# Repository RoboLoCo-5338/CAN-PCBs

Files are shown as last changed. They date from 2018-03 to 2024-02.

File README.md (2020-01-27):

# Quick Overview
The goal of this project was to create a Printed Circuit Board (PCB) for our Controller Area Network (CAN) Bus using a star topology for our robot.
You can learn more CAN and various topologies [here](http://www.mindsensors.com/content/86-can-and-its-topology).
Each v7 and v8 board was designed to accommodate up to **10** CAN devices, i.e., 8 Victor SPXs or Talon SRXs along with a Power Distribution Panel and RoboRIO.
The v9 board allows for up to **24** connections per board including a "ground" connection for each. 

Easy expansion is possible by linking multiple boards to each other directly to increase the total number of connections, i.e., 2 boards allows for 18 total connections.
When combined with code that is fault-tolerant, it can be possible to recover from the loss or disconnection of a device on the bus, which would be catastrophic on a daisy-chained network.

This project contains two folders, one for the PCB that our team currently uses on our competition robot, as well as one for the PCB that we plan to handout at the Chesapeake District Championships.

We have used these boards since the 2017/2018 season and are satisfied with their excellent performance and ease of wiring.

# RoboLoCo
* [RoboLoCo's Website](https://www.roboloco.org)
* [CAN PCB Website](https://www.roboloco.org/canpcb)

# PCB Specifics
The PCB uses screw terminals to connect devices to the bus.
They, such as the ones we use from [Amazon](https://www.amazon.com/gp/product/B00EZ3QPCU/), are standard Wago 237-132 screw terminals.
We have found it ideal when the CAN wires are placed in ferrules, such as the ones we use from [Automation Direct](https://www.automationdirect.com/adc/Shopping/Catalog/Wiring_Solutions/BM_Group_-_Wire_End_Connectors/Insulated_Ferrules/DIN_Color_Single_Wire/BM-00601), but that is not required.
The terminating 120Ω resistors are optional in almost every use case and are for extra future functionality to not require the use of two devices with built in termination.
However, should a 120Ω resistors be added, its corresponding optional male headers **must** be added to enable or disable the resistors.

# Holder and Mounting Info
The PCBs' holders were also designed to fit on standard 1" pegboard via zip ties or bolts.
The holes on each holder was designed to accommodate heat-set inserts, such as the ones we use from [McMaster-Carr](https://www.mcmaster.com/#93365a132/=1b46wa6), to provide threaded holes.
The board then uses at up to 6 0.1875" #6-32 bolts depending on the PCB, such as the ones we use from [McMaster-Carr](https://www.mcmaster.com/#91864a085/), to be anchored down.
Particularly, the spacing around the center holes allows for the use of thumb screws, such as the ones we use from [Amazon](https://www.amazon.com/Anodized-Aluminum-Computer-Thumbscrews-Thread/dp/B00BGZ1OFI/), to allow for easier insertion and removal before final mounting.

# Files
For each board, the files provided include the Eagle BRD, SCH, and EPF files, as well as STL files for the 3D printed holder.
The files are compatible with [Eagle](https://www.autodesk.com/products/eagle/free-download) 8.0 and up.
The DRU file used by our PCB fab, [Silver Circuits](http://www.custompcb.com), is also provided. However, the Eagles files can be used to manufacture the board with the PCB fab of your choice
For each board, there are also images of the board layout and schematic in Eagle, a render of the holder, and images of the actual PCB in the 3D-printed holder.

# Versions

## Star Board v7 (aka Competition PCB)
This is a current production board that is tested and in use on RoboLoCo's 2019 robot. 

## Star Board v8
This is incomplete and under active development. 

## Star Board Wide v9
### Overview
This is a current production board that is tested and in use on RoboLoCo's 2020 robot. 

### "Ground" Connection
For FRC the "ground" on the board should be used with the sheild on sheilded twisted pair cable. RoboLoCo is leaving it to float. 
It's possible to attach to either the neg power or chassis. However both options carry slight risks during inspection. If attached to the 
chassis any instance of the shield touching **any** electrical connections even slightly will cause the chassis to be electrically connected 
to the electrical system. A related issue happens if using the chassis for the sheild. 

# Final Notes
If you have any questions, feel reach out and contact us at contact@roboloco.org.
Please share with us your experiences if you use them and any feedback you have!

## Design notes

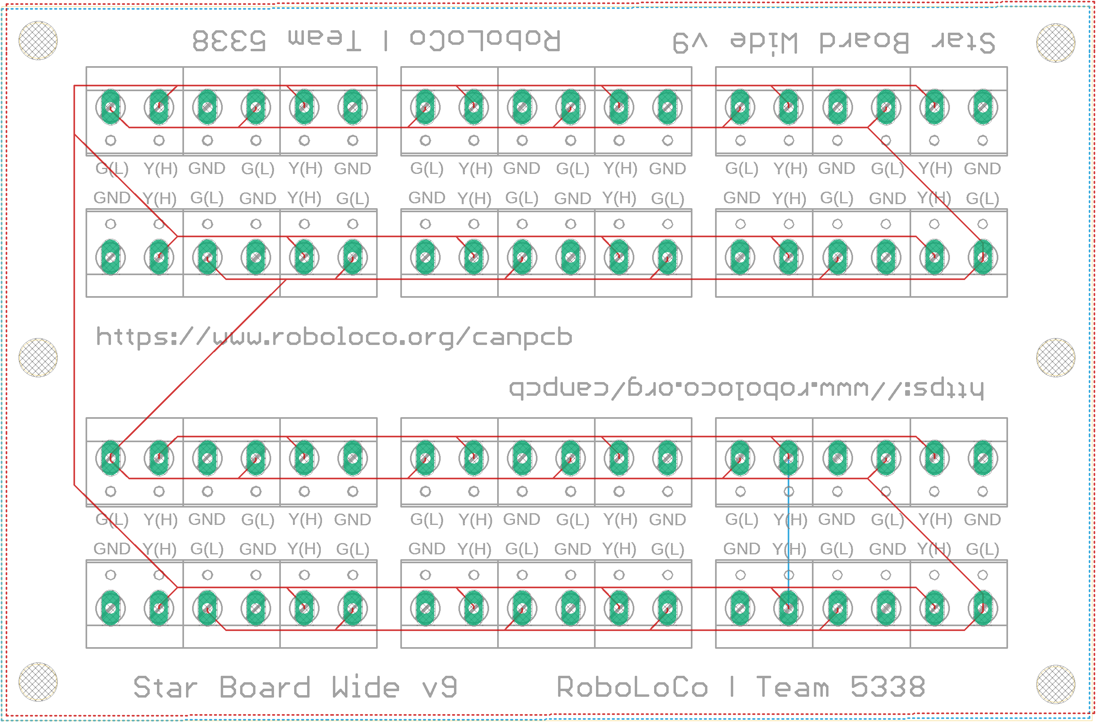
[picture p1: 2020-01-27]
Star Board Wide v9/Images/board.png

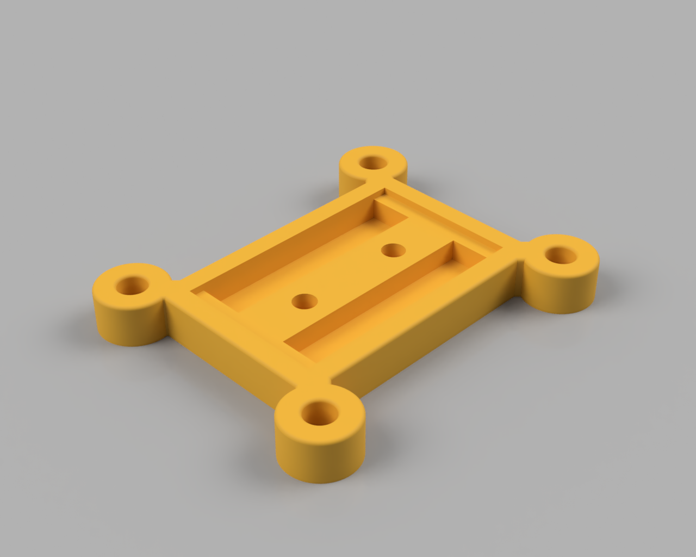
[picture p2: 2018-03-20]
District Champs PCB - Depricated/Holder/Holder.PNG

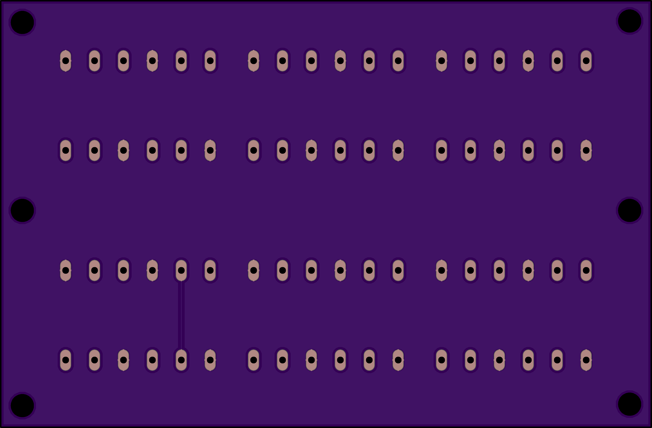
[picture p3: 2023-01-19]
Star Board Wide v9/PCB/FAB_Files/bottom.png

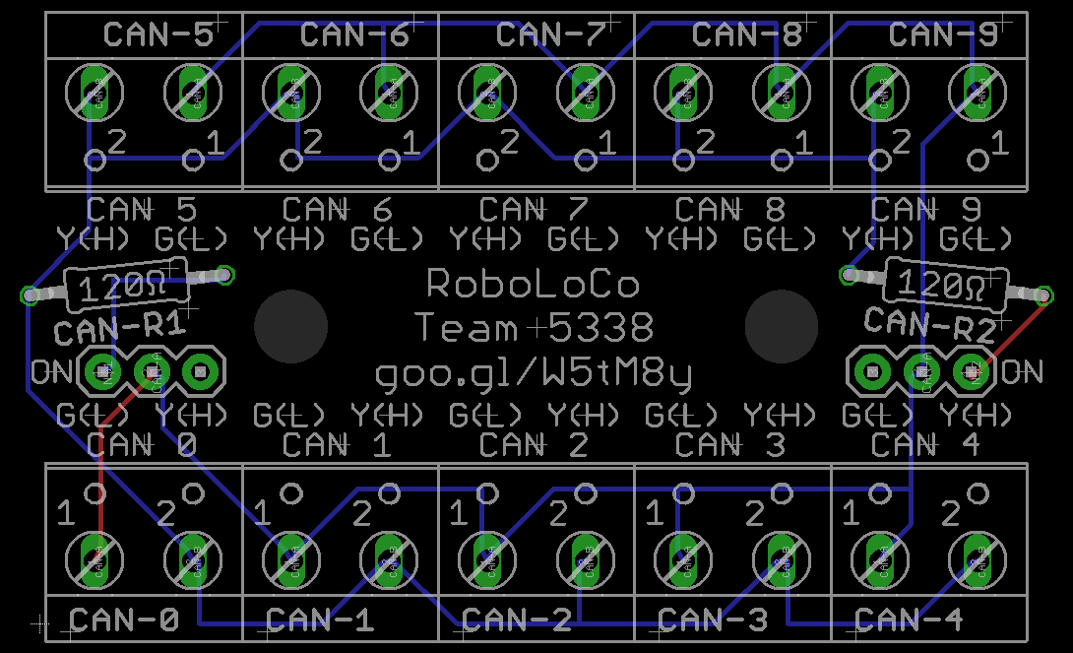
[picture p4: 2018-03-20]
District Champs PCB - Depricated/PCB/PCB.png

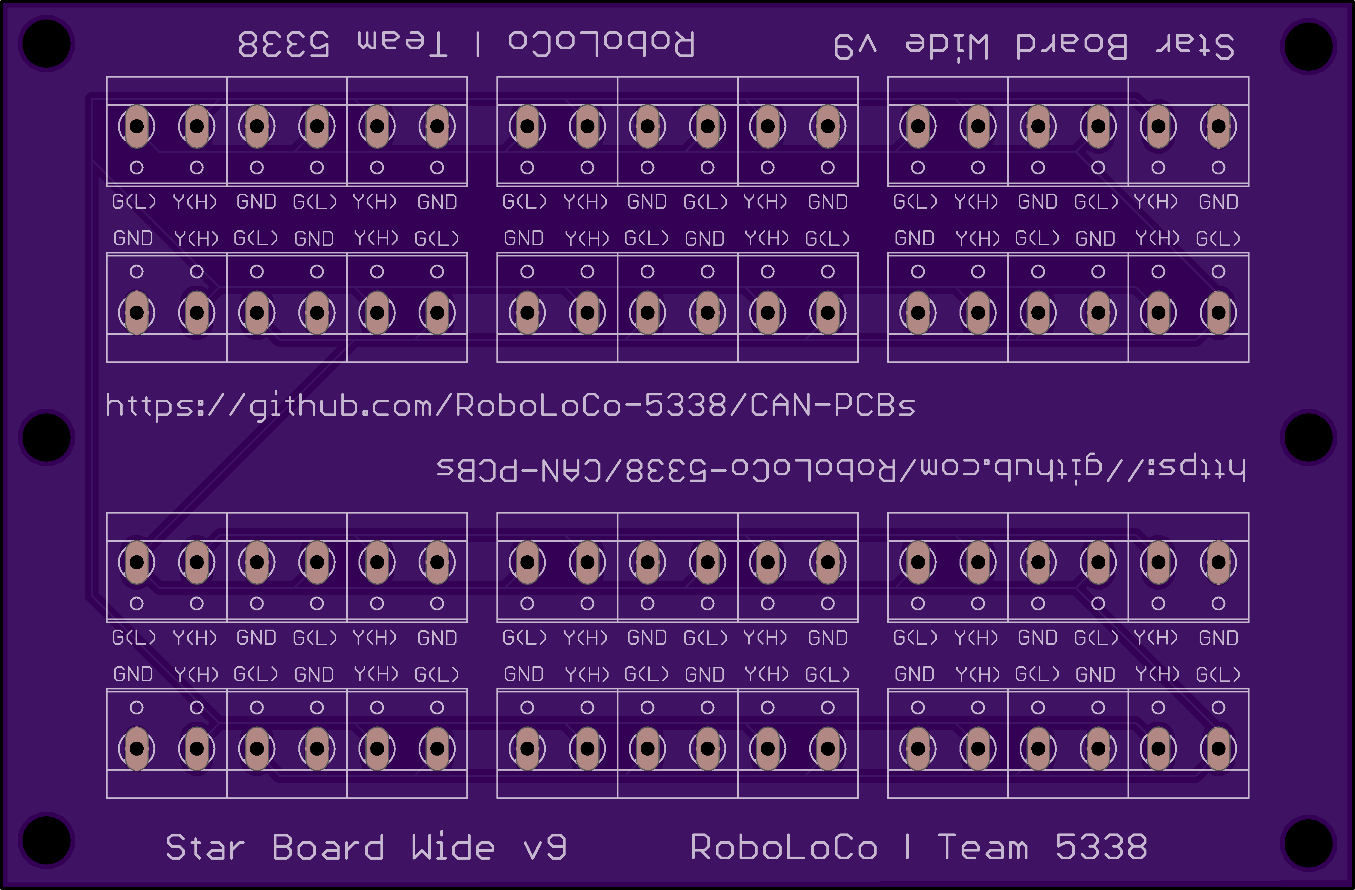
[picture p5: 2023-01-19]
Star Board Wide v9/PCB/FAB_Files/top.png

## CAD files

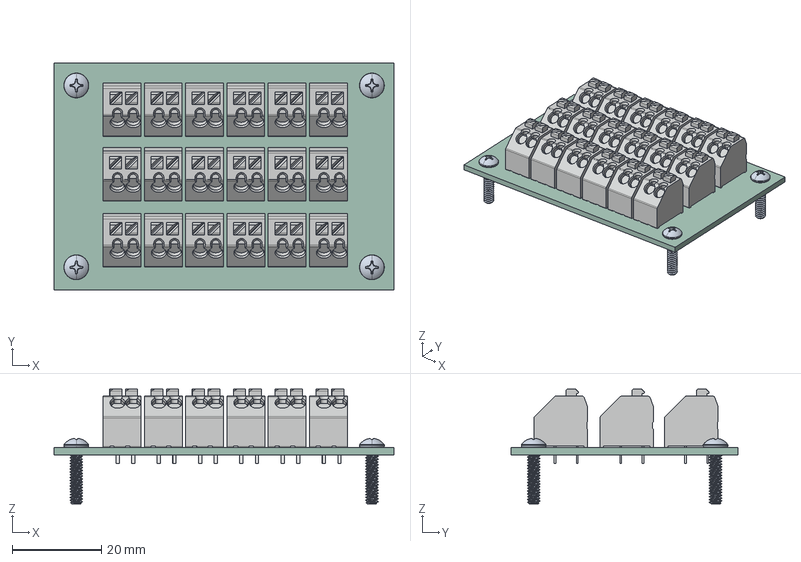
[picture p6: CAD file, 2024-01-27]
Star Board v10/Model/CAN_board.step
76.2 x 50.8 x 25.8 mm
91772A110_Passivated 18-8 Stainless Steel Pan Head Phillips Screw x 4
_autosave-CAN_board PCB

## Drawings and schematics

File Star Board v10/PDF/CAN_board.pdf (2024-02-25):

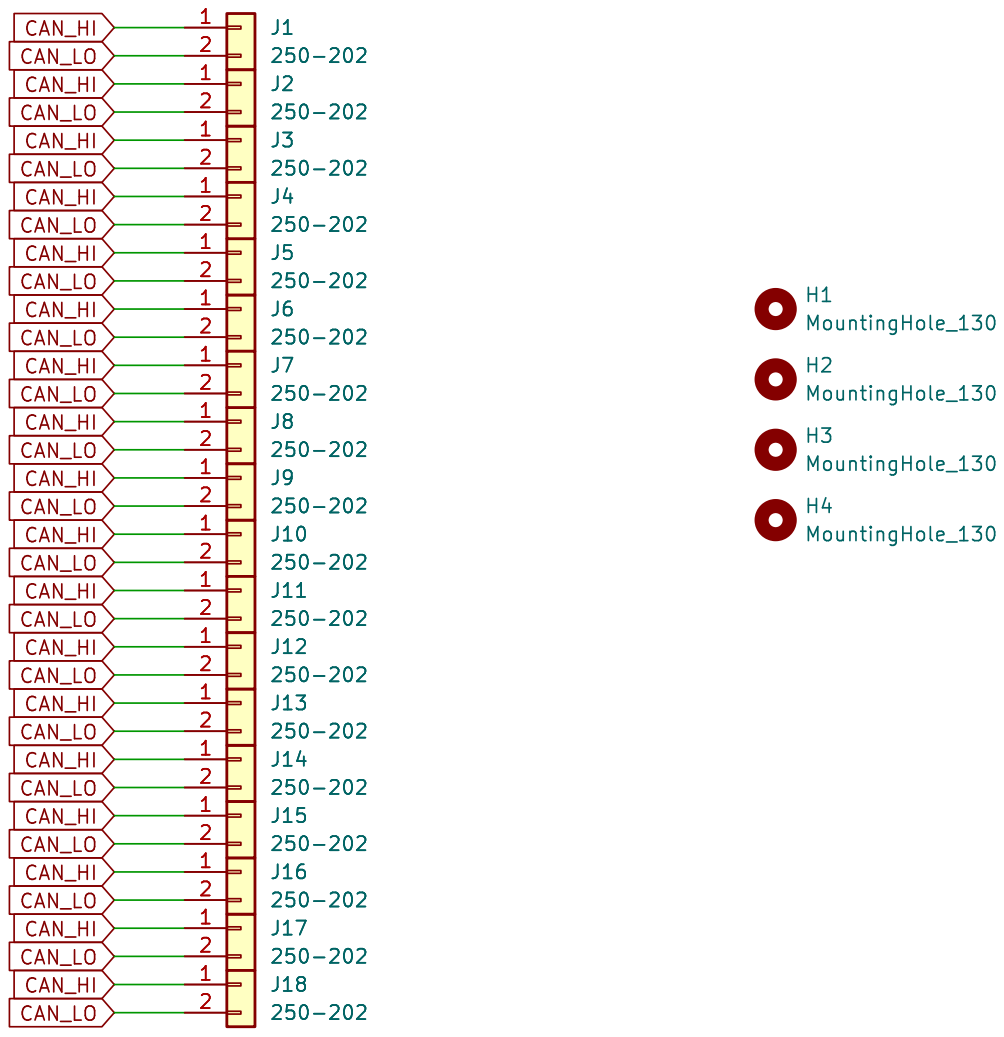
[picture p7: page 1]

Id: 1/1 Title: File: CAN_board.kicad_sch Sheet: / 12

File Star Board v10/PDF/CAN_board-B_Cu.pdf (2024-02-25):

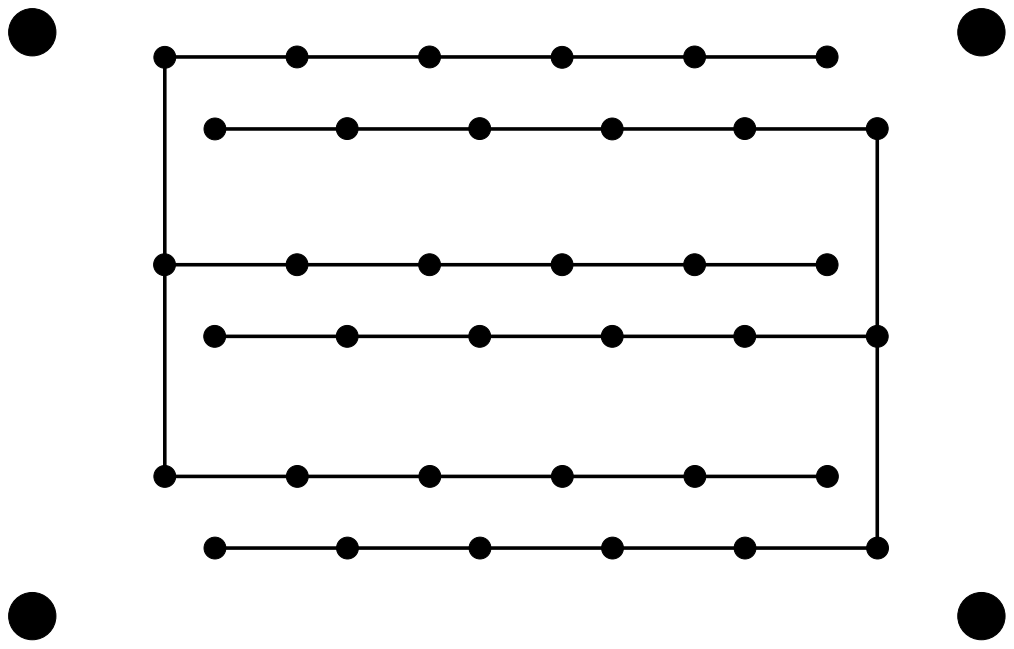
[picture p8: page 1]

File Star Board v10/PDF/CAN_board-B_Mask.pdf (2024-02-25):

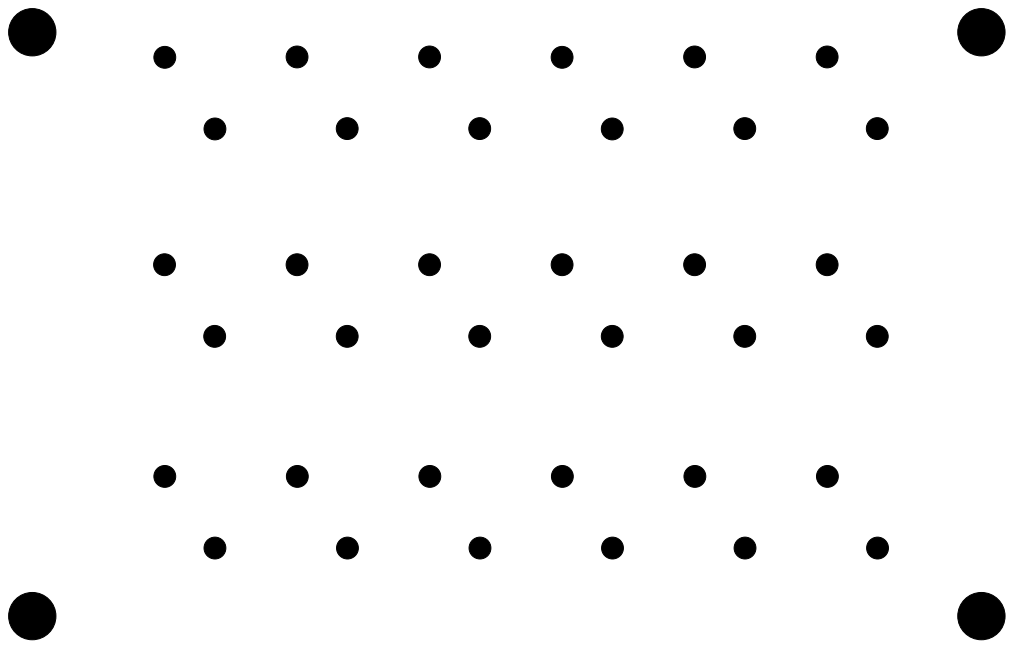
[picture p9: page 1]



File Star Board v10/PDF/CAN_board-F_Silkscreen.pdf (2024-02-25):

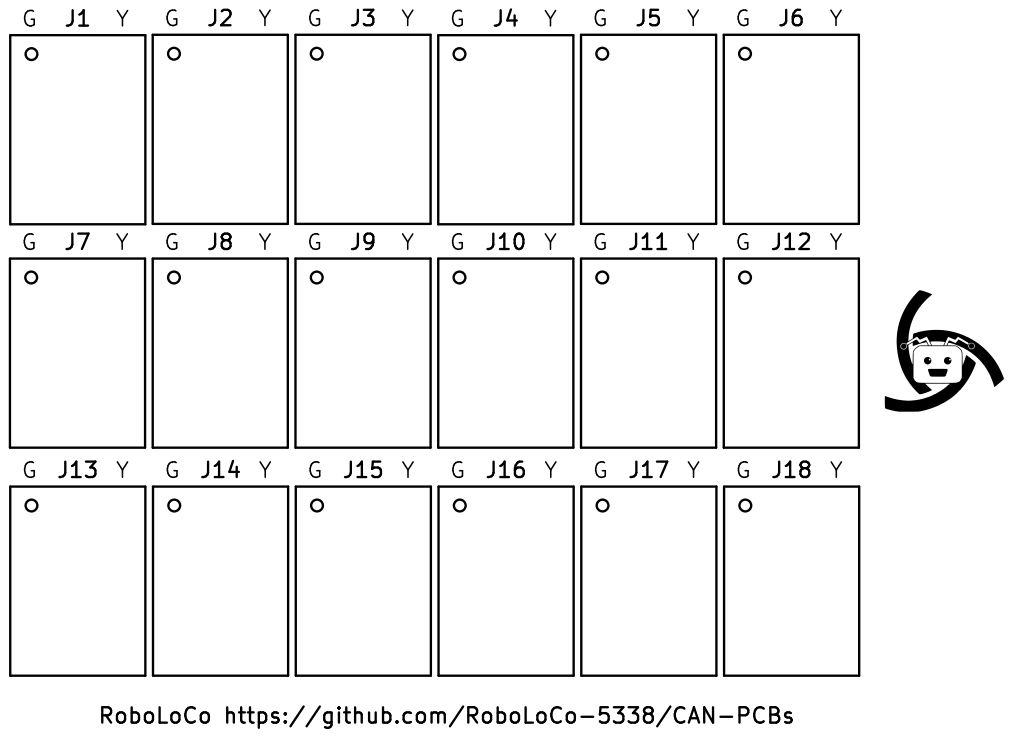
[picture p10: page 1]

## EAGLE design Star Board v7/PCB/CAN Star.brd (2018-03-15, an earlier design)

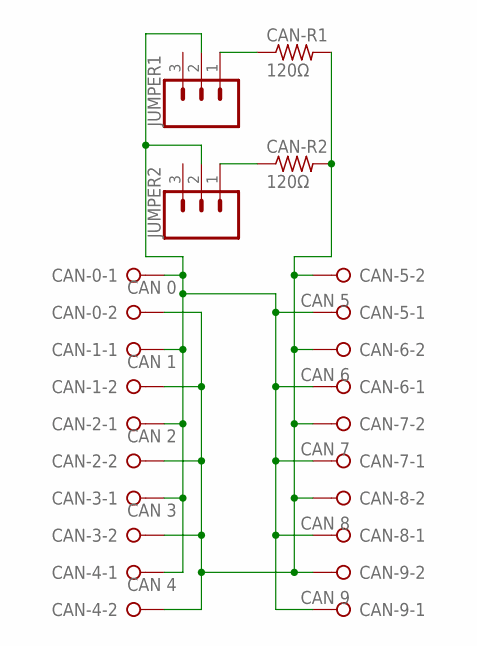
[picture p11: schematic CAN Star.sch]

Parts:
CAN-0: CAN 0; W237-132
CAN-1: CAN 1; W237-132
CAN-2: CAN 2; W237-132
CAN-3: CAN 3; W237-132
CAN-4: CAN 4; W237-132
CAN-5: CAN 5; W237-132
CAN-6: CAN 6; W237-132
CAN-7: CAN 7; W237-132
CAN-8: CAN 8; W237-132
CAN-9: CAN 9; W237-132
CAN-R1, CAN-R2: 120Ω; 0207/10
JUMPER1, JUMPER2: CONN_03; 1X03

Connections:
CAN-A: CAN-0.1, CAN-1.1, CAN-2.1, CAN-3.1, CAN-4.1, CAN-5.1, CAN-6.1, CAN-7.1, CAN-8.1, CAN-9.1, JUMPER1.2, JUMPER2.2
CAN-B: CAN-0.2, CAN-1.2, CAN-2.2, CAN-3.2, CAN-4.2, CAN-5.2, CAN-6.2, CAN-7.2, CAN-8.2, CAN-9.2, CAN-R1.2, CAN-R2.2
unnamed: CAN-R1.1, JUMPER1.1
unnamed: CAN-R2.1, JUMPER2.1

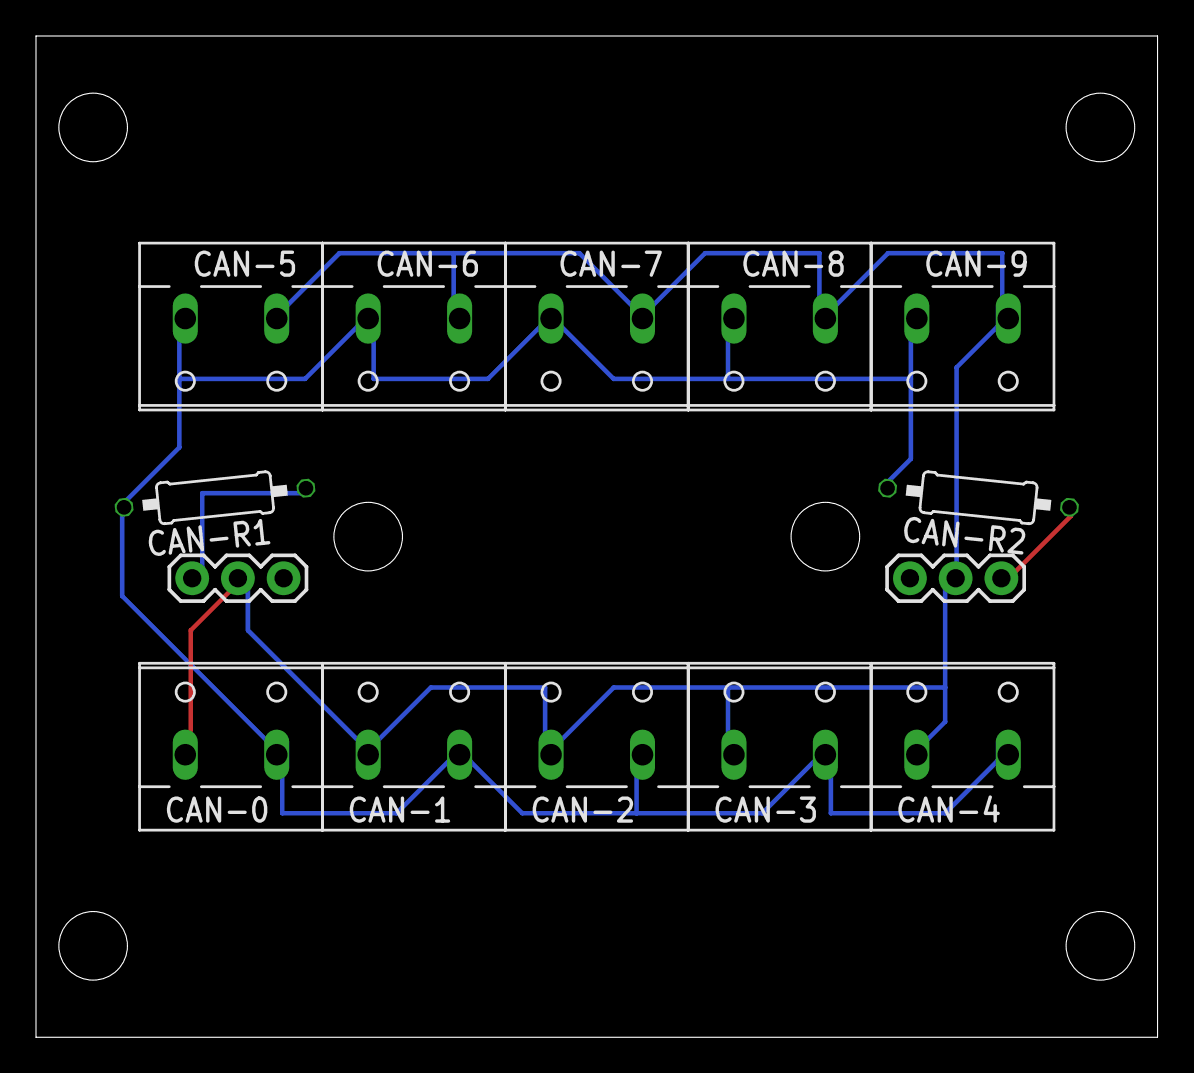
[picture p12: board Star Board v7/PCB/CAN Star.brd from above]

Board: 2 copper layers, 62.3 x 55.6 mm, 14 parts (0 on the bottom side), 4 nets.

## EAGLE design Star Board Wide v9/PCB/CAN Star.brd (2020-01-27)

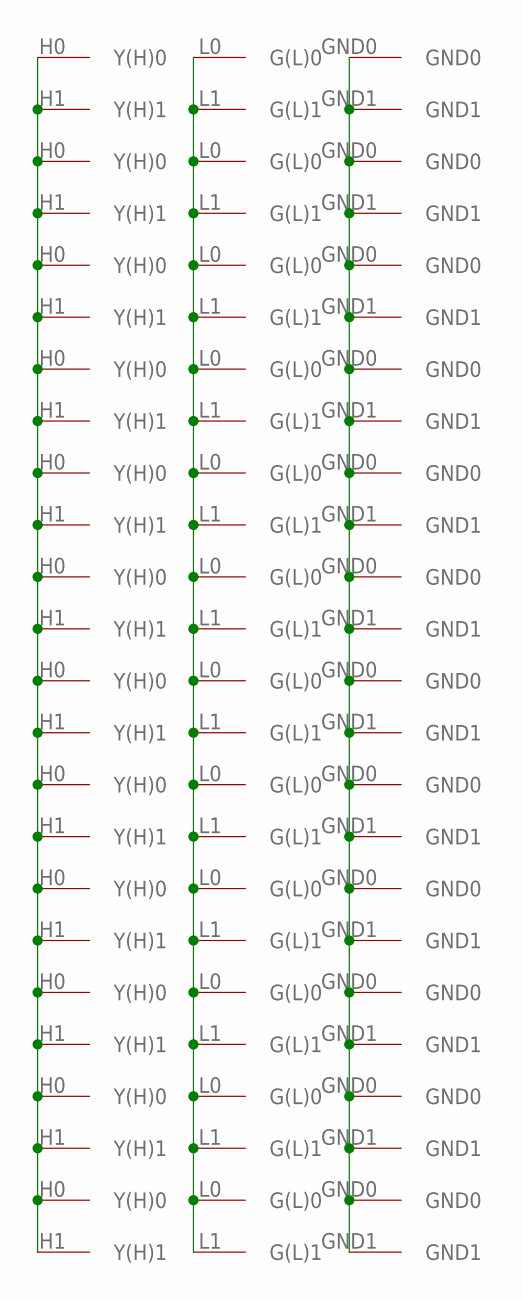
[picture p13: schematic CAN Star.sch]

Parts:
U$1, U$2, U$3, U$4, U$5, U$6, U$7, U$8, U$9, U$10, U$11, U$12: 2-3-TERMS; GREEN-2-TERMS

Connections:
G(L): U$1.L0 (G(L)0), U$1.L1 (G(L)1), U$2.L0 (G(L)0), U$2.L1 (G(L)1), U$3.L0 (G(L)0), U$3.L1 (G(L)1), U$4.L0 (G(L)0), U$4.L1 (G(L)1), U$5.L0 (G(L)0), U$5.L1 (G(L)1), U$6.L0 (G(L)0), U$6.L1 (G(L)1), U$7.L0 (G(L)0), U$7.L1 (G(L)1), U$8.L0 (G(L)0), U$8.L1 (G(L)1), U$9.L0 (G(L)0), U$9.L1 (G(L)1), U$10.L0 (G(L)0), U$10.L1 (G(L)1), U$11.L0 (G(L)0), U$11.L1 (G(L)1), U$12.L0 (G(L)0), U$12.L1 (G(L)1)
GND: U$1.GND0, U$1.GND1, U$2.GND0, U$2.GND1, U$3.GND0, U$3.GND1, U$4.GND0, U$4.GND1, U$5.GND0, U$5.GND1, U$6.GND0, U$6.GND1, U$7.GND0, U$7.GND1, U$8.GND0, U$8.GND1, U$9.GND0, U$9.GND1, U$10.GND0, U$10.GND1, U$11.GND0, U$11.GND1, U$12.GND0, U$12.GND1
Y(H): U$1.H0 (Y(H)0), U$1.H1 (Y(H)1), U$2.H0 (Y(H)0), U$2.H1 (Y(H)1), U$3.H0 (Y(H)0), U$3.H1 (Y(H)1), U$4.H0 (Y(H)0), U$4.H1 (Y(H)1), U$5.H0 (Y(H)0), U$5.H1 (Y(H)1), U$6.H0 (Y(H)0), U$6.H1 (Y(H)1), U$7.H0 (Y(H)0), U$7.H1 (Y(H)1), U$8.H0 (Y(H)0), U$8.H1 (Y(H)1), U$9.H0 (Y(H)0), U$9.H1 (Y(H)1), U$10.H0 (Y(H)0), U$10.H1 (Y(H)1), U$11.H0 (Y(H)0), U$11.H1 (Y(H)1), U$12.H0 (Y(H)0), U$12.H1 (Y(H)1)

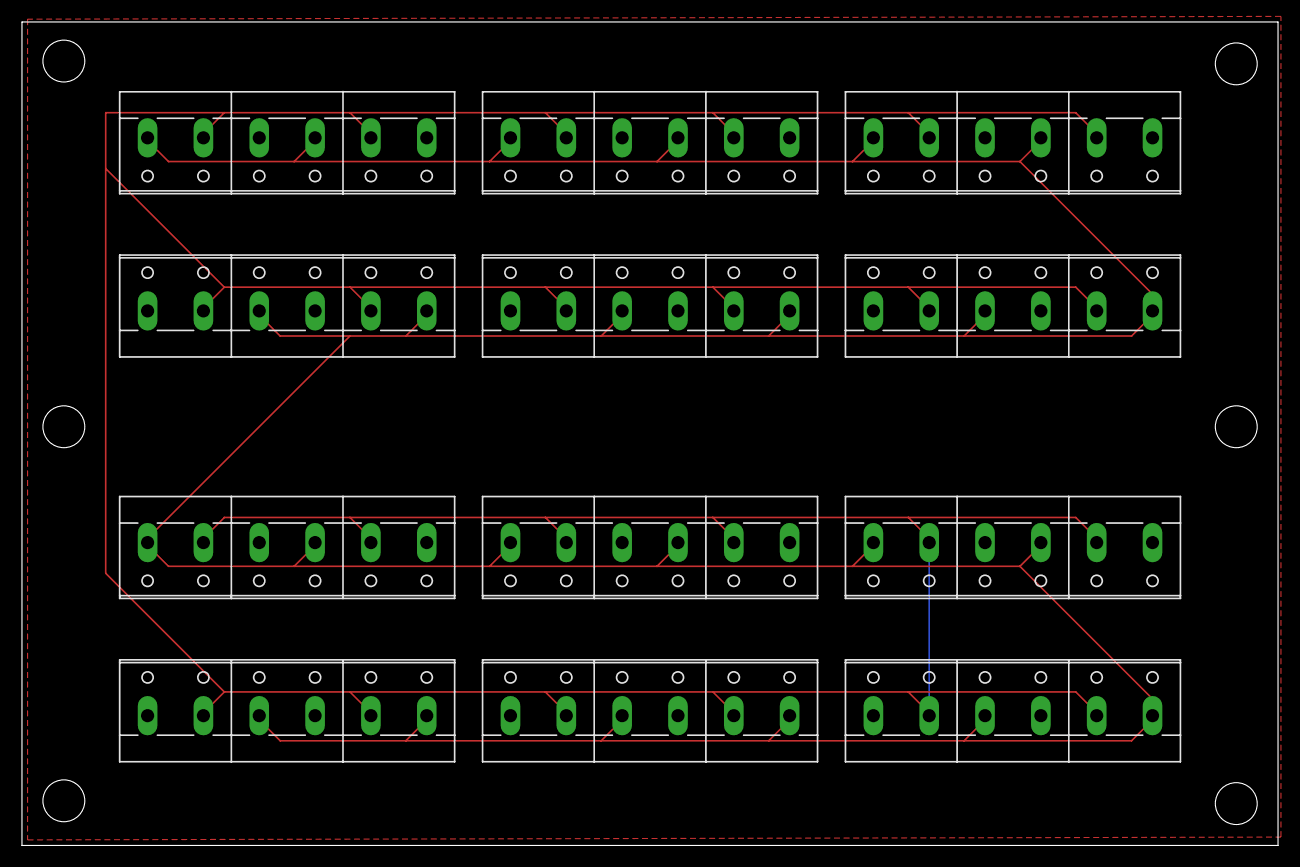
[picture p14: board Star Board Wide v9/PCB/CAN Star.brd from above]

Board: 2 copper layers, 114.3 x 74.9 mm, 12 parts (0 on the bottom side), 3 nets.

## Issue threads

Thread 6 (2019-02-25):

Larger Board

gpmidi, 2019-02-25:
RoboLoCo frequently has to use two boards. Perhaps we should have a 20-slot board too...

gpmidi, 2019-02-27:
Done in 04b598c4c8c504f9d63e71f4c1ac8e1baa8ae0e2

Closed 2019-02-27.

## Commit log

2017-12-09 Initial File Uploads
    [CAN Line PCB Holder.stl, CAN Line.brd, CAN Line.sch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]
2017-12-15 Updated Eagle Files
    [CAN Star.brd, CAN Star.sch]
2017-12-18 Updated with strain relief holes, but not finalized yet.
    [CAN Star.brd]
2017-12-23 Finalized Star PCB
    [CAN Star.brd, CAN Star.sch]
2017-12-23 Added additional mounting holes
    [CAN Star.brd]
2017-12-24 Removed old files
    [CAN Line PCB Holder.stl, CAN Line.brd, CAN Line.sch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]
2017-12-25 Finalized Star PCB Design
    [CAN Star.brd, CAN Star.sch]
2017-12-25 Actually uploaded the right version ;)
    [CAN Star.brd]
2017-12-25 Beginning update of Line PCB and Holder
    [CAN Line.brd, CAN Line.sch]
2018-01-11 Updated Star PCB design and added finalized holder
    [CAN Star.brd]
2018-01-14 Updated STL, Images, Eagle Files, and the README to make it more descriptive and informative
    [CAN Line.brd, CAN Line.sch, CAN Star.brd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]
2018-01-15 Updated README, adjusted holder, and cleaned up github repo
    [CAN Star.brd, CAN Star.sch]
2018-02-04 Updated README, renamed files, improved holder STL export, added additional images
2018-03-15 Updated to the version that we are planning on handing out at District Champs
    [CAN Star.brd, CAN Star.sch]
2018-03-19 Prepared folders and layout to contain two PCB versions, the one we hand out and one we personally use.
    [CAN Star.brd, CAN Star.sch]
2018-03-20 Updated with finalized files for District Champs PCB Gift, including a new holder stl and image, along with a smaller board with the url on it eagle files and image.
    [CAN Star.brd]
2018-03-21 Adjusted folder names and holders
    [CAN Star.brd, CAN Star.sch]
2018-05-06 Updated folder structure and made sure the correct .brd/.sch files were in the system so that future reorders by the team will be correct
    [CAN Star.brd, CAN Star.sch]
2019-02-27 Adding skel for Star Board v8
    [CAN Star.brd, CAN Star.sch]
2019-02-27 Don't want backup boards
2019-02-27 Created StarBoard v8
    [CAN Star.brd]
2019-02-27 Created v8 wide board
    [CAN Star.brd, CAN Star.sch]
2019-02-27 Unlocked and fixed view
    [CAN Star.brd]
2019-08-10 switch to wide-v9, add in grounds, removed odd connections, needs layout work
    [CAN Star.brd, CAN Star.sch]
2019-08-10 change layout to 3 by 4
    [CAN Star.brd, CAN Star.sch]
2019-11-24 Remade board wide v9
    [CAN Star.brd, CAN Star.sch]
2019-11-24 Auto routed
    [CAN Star.brd, CAN Star.sch]
2019-11-24 Rerouted with better nets for gnd
    [CAN Star.brd, CAN Star.sch]
2020-01-12 Reduced lengh so that it'll be producible by custompbc.com
    [CAN Star.brd, CAN Star.sch]
2020-01-12 Updated some info
    [CAN Star.brd, DRILEGEND.CFG]
2020-01-12 Updated with ground pour
    [CAN Star.brd]
2020-01-12 Added copper pour to top layer too
    [CAN Star.brd]
2020-01-27 Cleanup and wide v8 rename to v9
    [CAN Star.brd, CAN Star.sch, DRILEGEND.CFG]
2020-01-27 Rename of comp pcb -> v7 & doc update for wide v9
    [CAN Star.brd, CAN Star.sch]
2023-01-19 Updated web address on silkscreen

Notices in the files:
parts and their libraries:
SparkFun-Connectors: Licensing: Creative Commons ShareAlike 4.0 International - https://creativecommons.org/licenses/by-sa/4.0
